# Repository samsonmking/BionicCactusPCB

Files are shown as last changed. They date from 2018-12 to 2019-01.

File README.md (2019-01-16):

PCB Image

| Output | Current Rating (A)|
|---|---|
|Light | 3 |
|Pump Motor| 3 |

Designed for 2oz Copper / 0.8mm thickness

Made with KiCad Version 4.07. Not yet compatible with version 5.

Download [Schematic PDF](https://github.com/samsonmking/BionicCactusPCB/raw/master/schematic.pdf)

Order on [OshPark here](https://oshpark.com/shared_projects/fiqfBO67)

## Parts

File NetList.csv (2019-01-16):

Reference | Quantity | Value | Footprint | Datasheet | Field4 | Field5 | Field6 | Field7 | Field8
C11 C12 C13 C14 C2 C6 | 6 | 10uF | Capacitors_SMD:C_1812_HandSoldering
C1 C10 C3 C4 C5 C7 C8 | 7 | 0.1uF | Capacitors_SMD:C_0805_HandSoldering
C9 | 1 | 10uF, 20V | Capacitors_Tantalum_SMD:CP_Tantalum_Case-V_EIA-7343-20_Hand
F1 | 1 | Fuse | Fuse_Holders_and_Fuses:BladeFuse-Mini_Keystone_3568
J1 | 1 | 12VCC | Connectors_Terminal_Blocks:TerminalBlock_bornier-2_P5.08mm
J2 | 1 | Pump | Connectors_Terminal_Blocks:TerminalBlock_bornier-2_P5.08mm
J3 | 1 | Light | Connectors_Terminal_Blocks:TerminalBlock_bornier-2_P5.08mm
J4 | 1 | Scale | TerminalBlocks_Phoenix:TerminalBlock_Phoenix_MPT-2.54mm_4pol
J5 | 1 | Soil | TerminalBlocks_Phoenix:TerminalBlock_Phoenix_MPT-2.54mm_3pol
J6 | 1 | Button_Header | Pin_Headers:Pin_Header_Straight_1x02_Pitch2.54mm
L1 | 1 | 3.3uH | Inductors_SMD:L_0805_HandSoldering
Q1 | 1 | BT4403 | TO_SOT_Packages_SMD:SOT-23_Handsoldering
Q2 | 1 | FDD9411L_F085 | TO_SOT_Packages_SMD:TO-252-2
R1 R5 R6 | 3 | 100 | Resistors_SMD:R_0805_HandSoldering
R2 | 1 | 10K | Resistors_SMD:R_0805_HandSoldering
R3 | 1 | 20K | Resistors_SMD:R_0805_HandSoldering
R4 | 1 | 8.2K | Resistors_SMD:R_0805_HandSoldering
U1 | 1 | DRIVER-TB6612FNG-O/C8/EL(SSOP24)_Parallel | DRIVER-TB6612FNG-O_C8_EL_SSOP24_:SSOP-24_5.3x8.2mm_Pitch0.65mm_tng_mod_parallel | Good | Stepping Motor Driver Ic Unipolor Copper Wire 8 | Toshiba | SSOP-24 Toshiba | 1.72 USD | TB6612FNG_O,C,8,EL
U2 | 1 | HX711 | Housings_SSOP:SOP-16_4.4x10.4mm_Pitch1.27mm
U3 | 1 | WeMos_mini | wemos_d1_mini:D1_mini_board
U4 | 1 | NCP1117-3.3_TO252 | TO_SOT_Packages_SMD:TO-252-2
U5 | 1 | NCP1117-5.0_TO252 | TO_SOT_Packages_SMD:TO-252-2
W1 | 1 | NET-TIE | net_tie:NET-TIE-0.3mm

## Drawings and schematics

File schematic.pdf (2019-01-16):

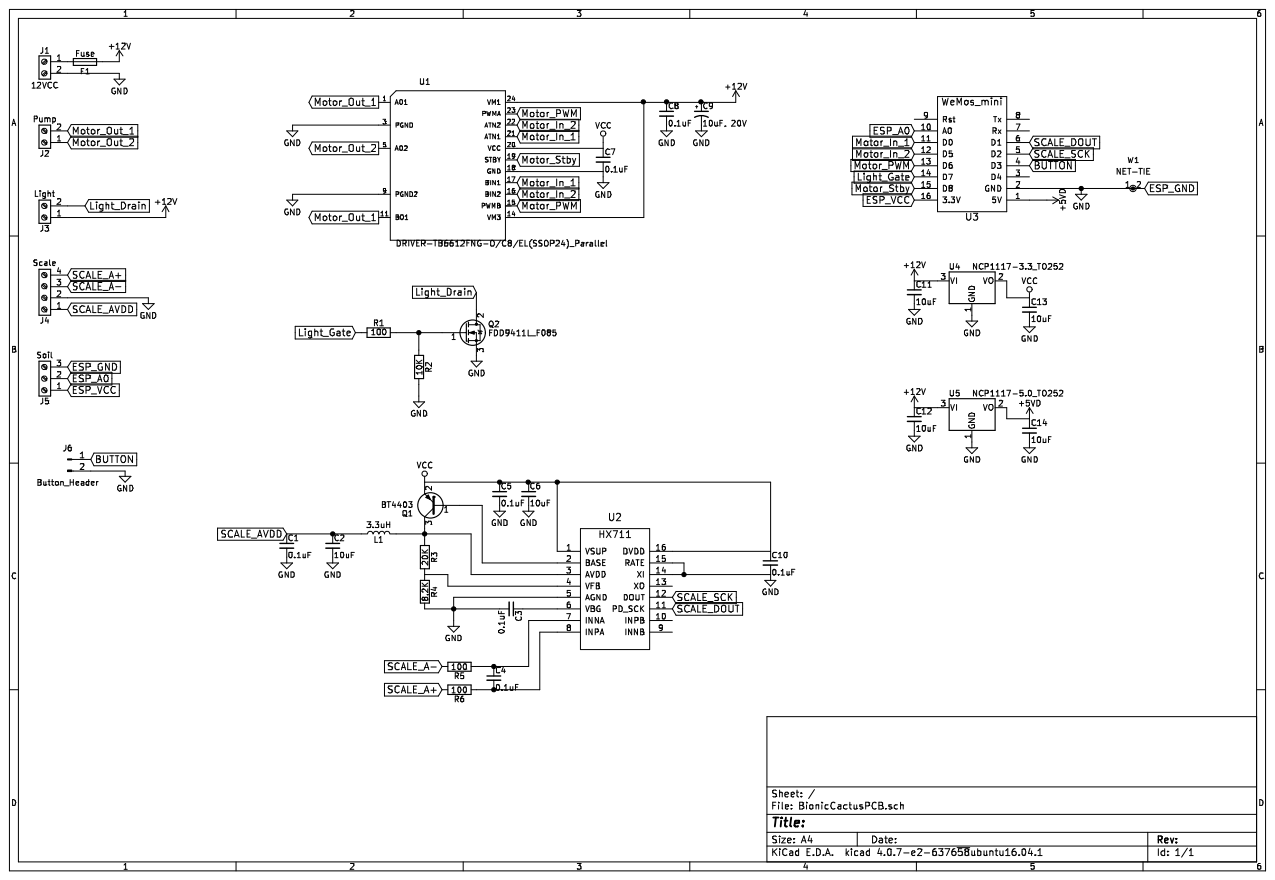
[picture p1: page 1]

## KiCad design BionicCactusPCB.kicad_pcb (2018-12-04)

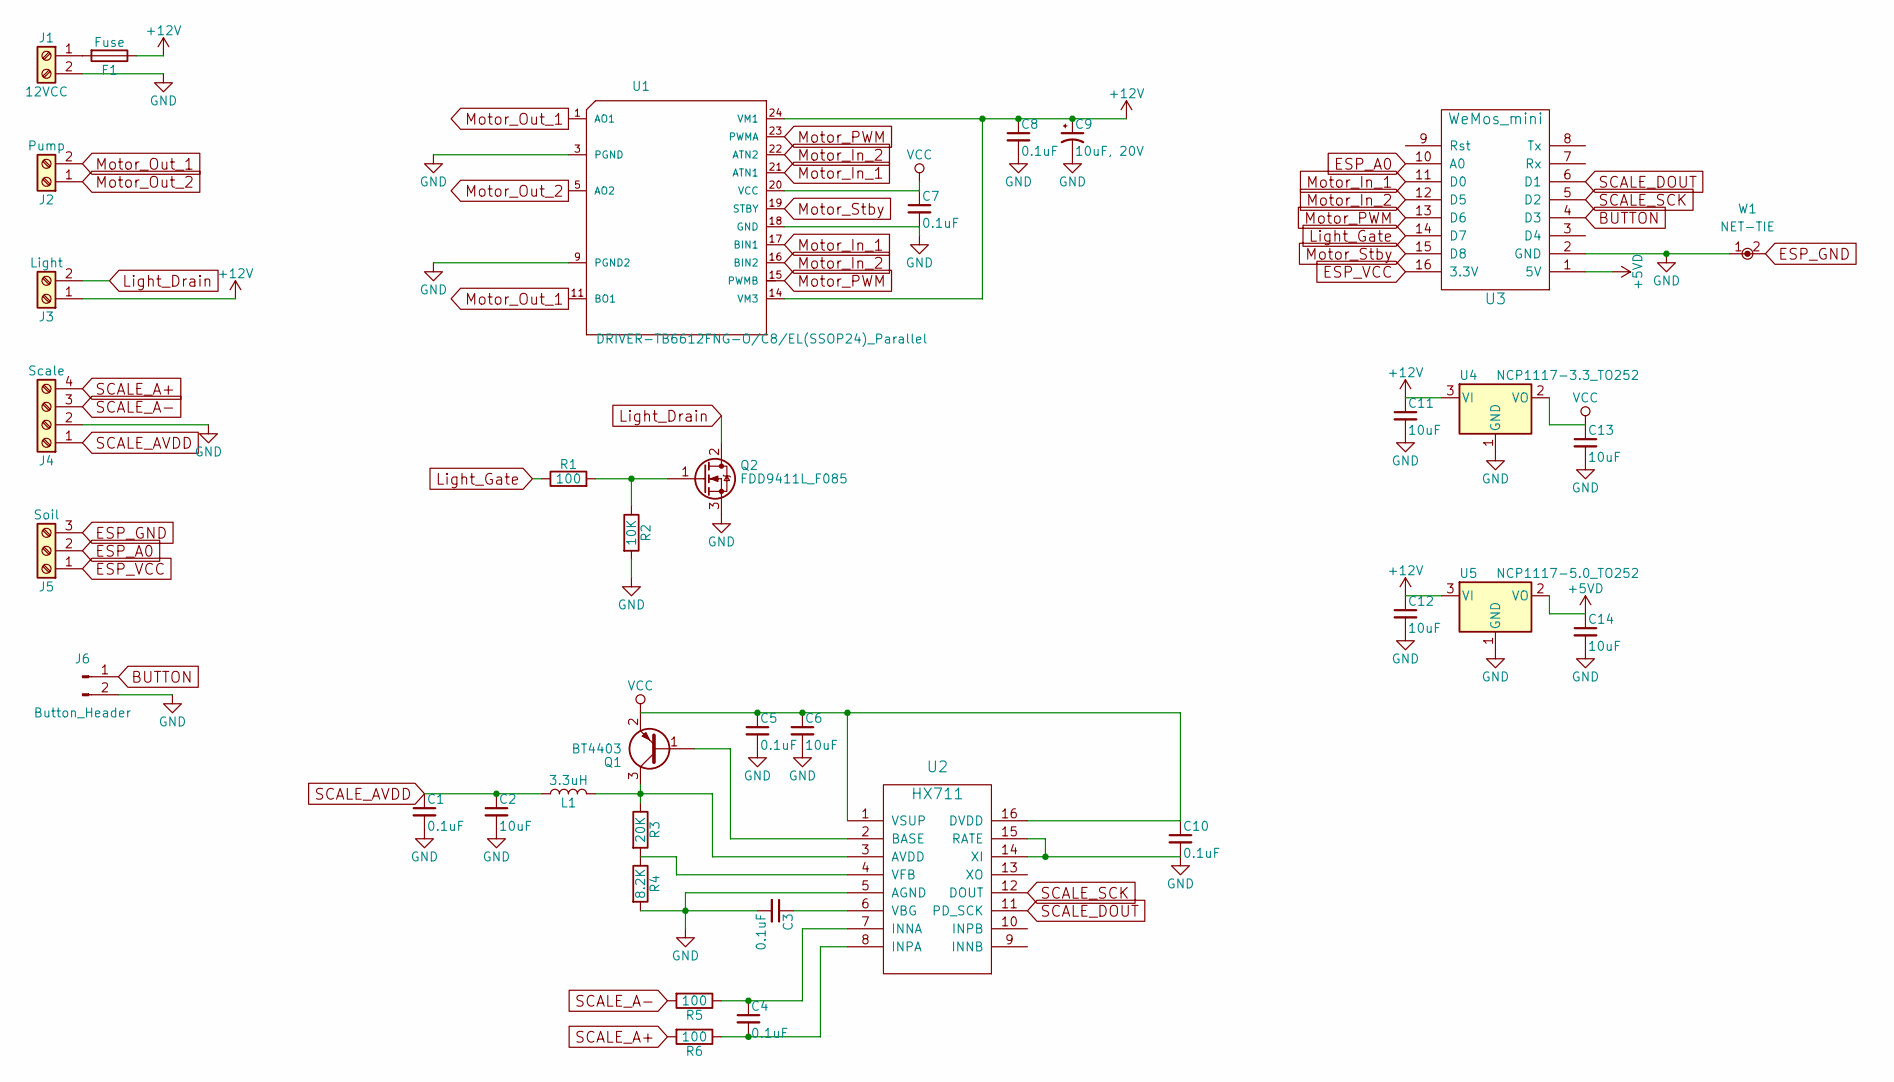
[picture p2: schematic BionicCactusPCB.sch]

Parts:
C1, C3, C4, C5, C7, C8, C10: 0.1uF; C_0805_HandSoldering
C2, C6, C11, C12, C13, C14: 10uF; C_1812_HandSoldering
C9: 10uF, 20V; CP_Tantalum_Case-V_EIA-7343-20_Hand
F1: Fuse; BladeFuse-Mini_Keystone_3568
J1: 12VCC; TerminalBlock_bornier-2_P5.08mm
J2: Pump; TerminalBlock_bornier-2_P5.08mm
J3: Light; TerminalBlock_bornier-2_P5.08mm
J4: Scale; TerminalBlock_Phoenix_MPT-2.54mm_4pol
J5: Soil; TerminalBlock_Phoenix_MPT-2.54mm_3pol
J6: Button_Header; Pin_Header_Straight_1x02_Pitch2.54mm
L1: 3.3uH; L_0805_HandSoldering
Q1: BT4403; SOT-23_Handsoldering
Q2: FDD9411L_F085; TO-252-2
R1, R5, R6: 100; R_0805_HandSoldering
R2: 10K; R_0805_HandSoldering
R3: 20K; R_0805_HandSoldering
R4: 8.2K; R_0805_HandSoldering
U1: DRIVER-TB6612FNG-O/C8/EL(SSOP24)_Parallel; SSOP-24_5.3x8.2mm_Pitch0.65mm_tng_mod_parallel
U2: HX711; SOP-16_4.4x10.4mm_Pitch1.27mm
U3: WeMos_mini; D1_mini_board
U4: NCP1117-3.3_TO252; TO-252-2
U5: NCP1117-5.0_TO252; TO-252-2
W1: NET-TIE; NET-TIE-0.3mm

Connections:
+5VD: C14.1, U3.1 (5V), U5.2 (VO)
+12V: C8.1, C9.1, C11.1, C12.1, F1.1, J3.1, U1.14 (VM3), U1.24 (VM1), U4.3 (VI), U5.3 (VI)
BUTTON: J6.1, U3.4 (D3)
ESP_A0: J5.2, U3.10 (A0)
ESP_GND: J5.3, W1.2
ESP_VCC: J5.1, U3.16 (3.3V)
GND: C1.2, C2.2, C3.2, C5.2, C6.2, C7.2, C8.2, C9.2, C10.2, C11.2, C12.2, C13.2, C14.2, J1.2, J4.2, J6.2, Q2.3 (S), R2.2, R4.2, U1.3 (PGND), U1.9 (PGND2), U1.18 (GND), U2.5 (AGND), U2.14 (XI), U2.15 (RATE), U3.2 (GND), U4.1 (GND), U5.1 (GND), W1.1
Light_Drain: J3.2, Q2.2 (D)
Light_Gate: R1.1, U3.14 (D7)
Motor_In_1: U1.17 (BIN1), U1.21 (ATN1), U3.11 (D0)
Motor_In_2: U1.16 (BIN2), U1.22 (ATN2), U3.12 (D5)
Motor_Out_1: J2.2, U1.1 (AO1), U1.11 (BO1)
Motor_Out_2: J2.1, U1.5 (AO2)
Motor_PWM: U1.15 (PWMB), U1.23 (PWMA), U3.13 (D6)
Motor_Stby: U1.19 (STBY), U3.15 (D8)
unnamed: C3.1, U2.6 (VBG)
unnamed: C4.1, R5.1, U2.7 (INNA)
unnamed: C4.2, R6.1, U2.8 (INPA)
unnamed: F1.2, J1.1
unnamed: L1.2, Q1.3 (C), R3.1, U2.3 (AVDD)
unnamed: Q1.1 (B), U2.2 (BASE)
unnamed: Q2.1 (G), R1.2, R2.1
unnamed: R3.2, R4.1, U2.4 (VFB)
SCALE_A+: J4.4, R6.2
SCALE_A-: J4.3, R5.2
SCALE_AVDD: C1.1, C2.1, J4.1, L1.1
SCALE_DOUT: U2.11 (PD_SCK), U3.6 (D1)
SCALE_SCK: U2.12 (DOUT), U3.5 (D2)
VCC: C5.1, C6.1, C7.1, C10.1, C13.1, Q1.2 (E), U1.20 (VCC), U2.1 (VSUP), U2.16 (DVDD), U4.2 (VO)

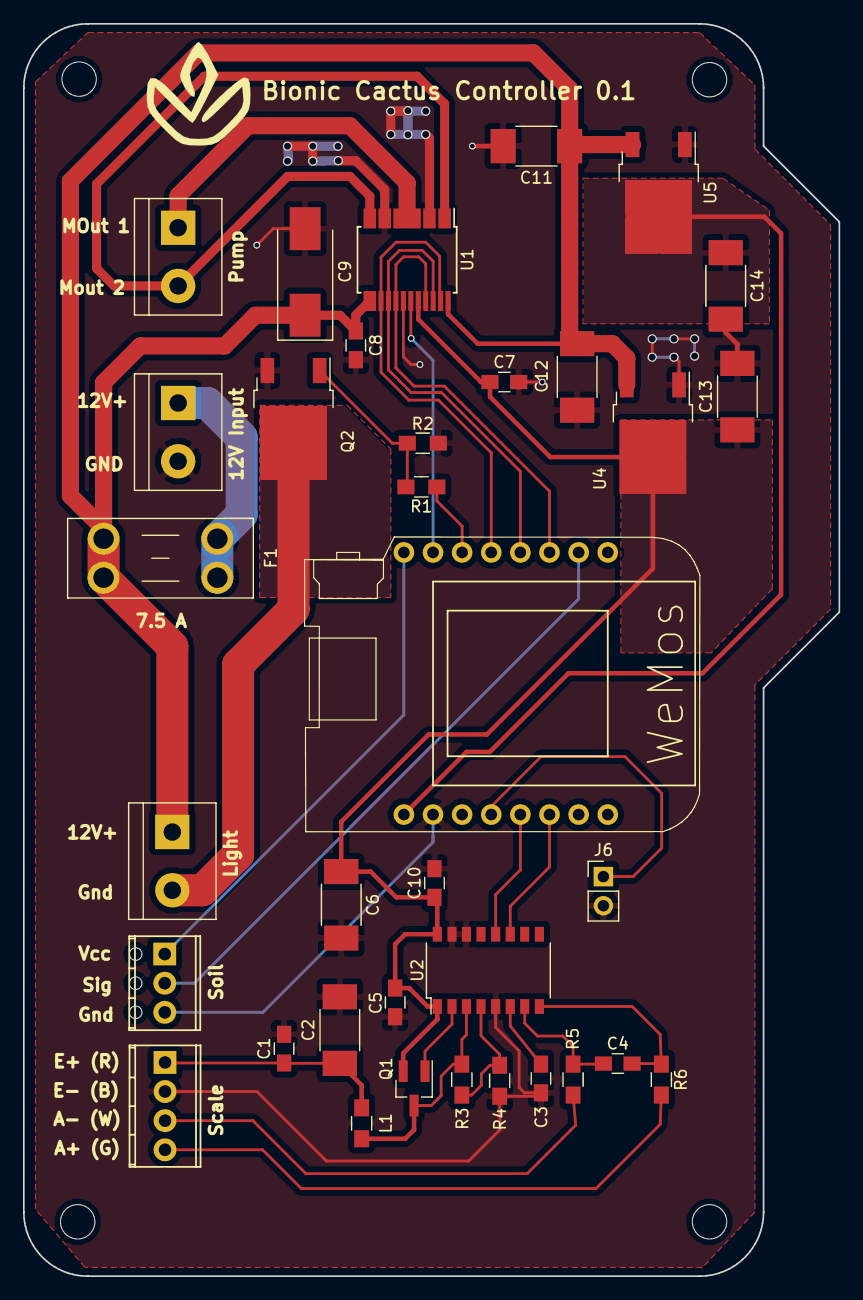
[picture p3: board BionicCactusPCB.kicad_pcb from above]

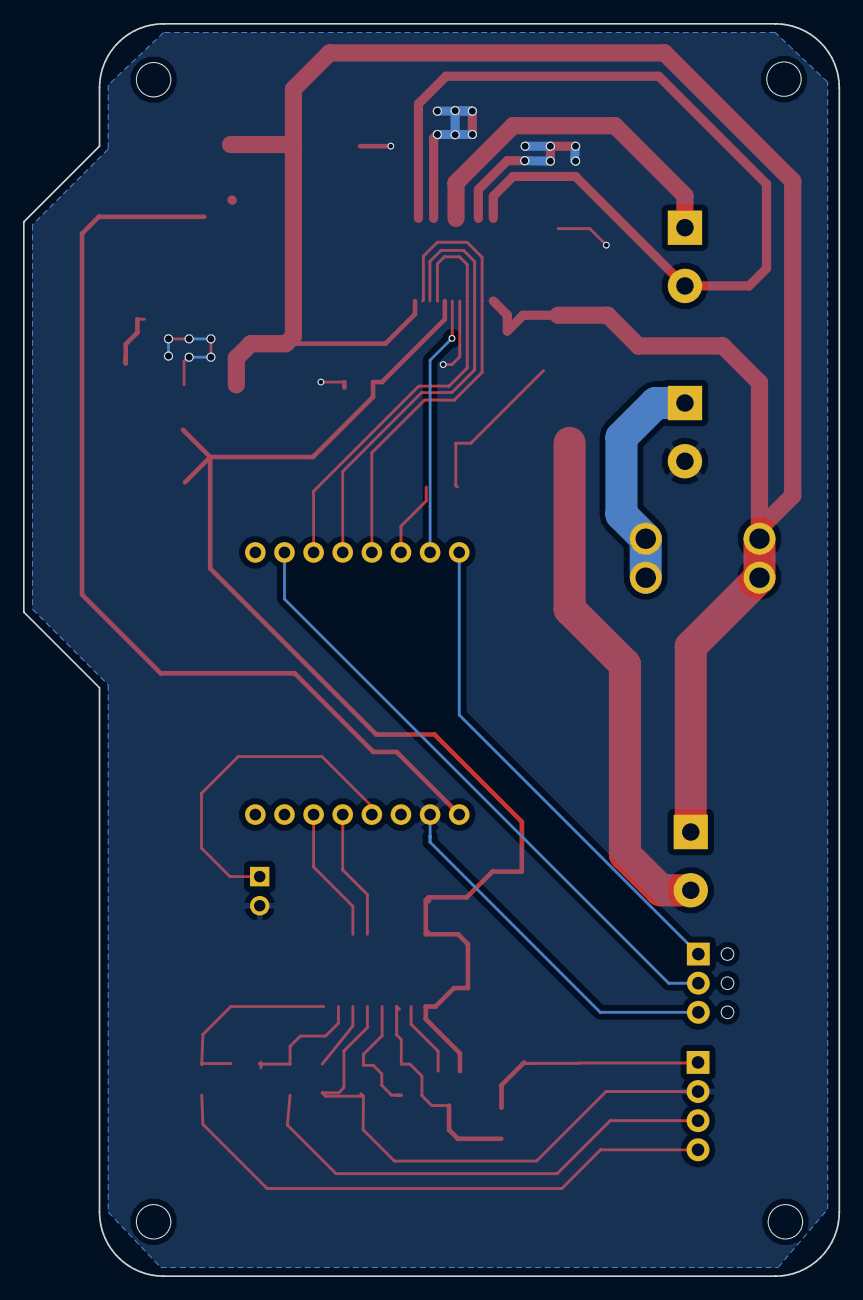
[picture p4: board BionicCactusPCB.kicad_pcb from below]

Board: 2 copper layers, 71.1 x 109.2 mm, 36 parts (2 on the bottom side), 29 nets.

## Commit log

2018-12-04 Initial commit working PCB
    [BionicCactusPCB.kicad_pcb, BionicCactusPCB.sch]
2019-01-16 Add schematic pdf and net list
    [NetList.csv]
2019-01-16 Add current and osh park link
